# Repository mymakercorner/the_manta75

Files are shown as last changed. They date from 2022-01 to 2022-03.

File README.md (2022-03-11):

# The Manta75

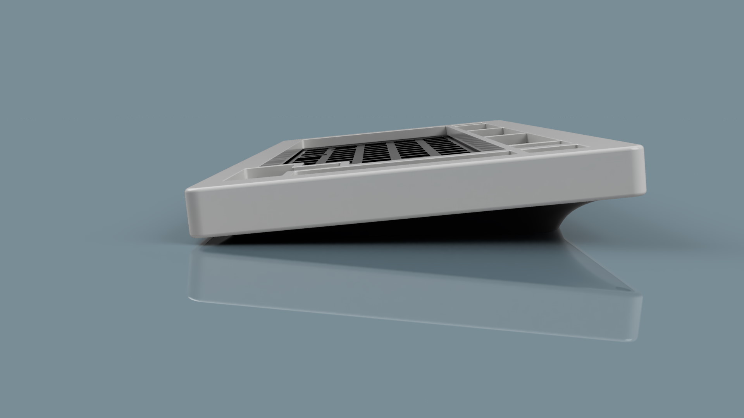
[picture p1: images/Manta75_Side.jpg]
Manta75 render


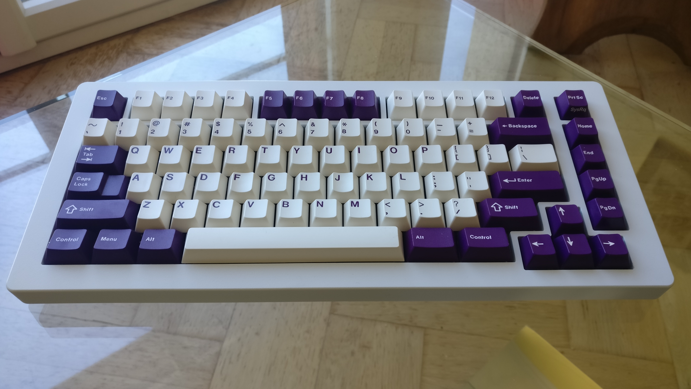
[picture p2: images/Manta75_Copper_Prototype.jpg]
Manta75 copper prototype


The Manta75 is an exploded arrows and nav clusters 75% keyboard with a curvy bottom.
It is the second project of the *Sea Collection* and as such it's name is taken from one of the species we see in our oceans, the [Manta ray](https://en.wikipedia.org/wiki/Manta_ray).

The [Satisfaction 75](https://cannonkeys.com/collections/satisfaction-75) have this similar exploded arrows/nav clusters, on the manta75 I went with no knob and screen to maximize the number of available keys.

## Features

- Two pieces case designed with Fusion360.
- PCB designed with Kicad 5.1.5.
- Bottom mount leaf spring plate design with optional friction fit gaskets.
- [Unified C3 daughterboard](https://github.com/ai03-2725/Unified-Daughterboard)
- QMK firmware with VIA and VIAL support.

## Layout options

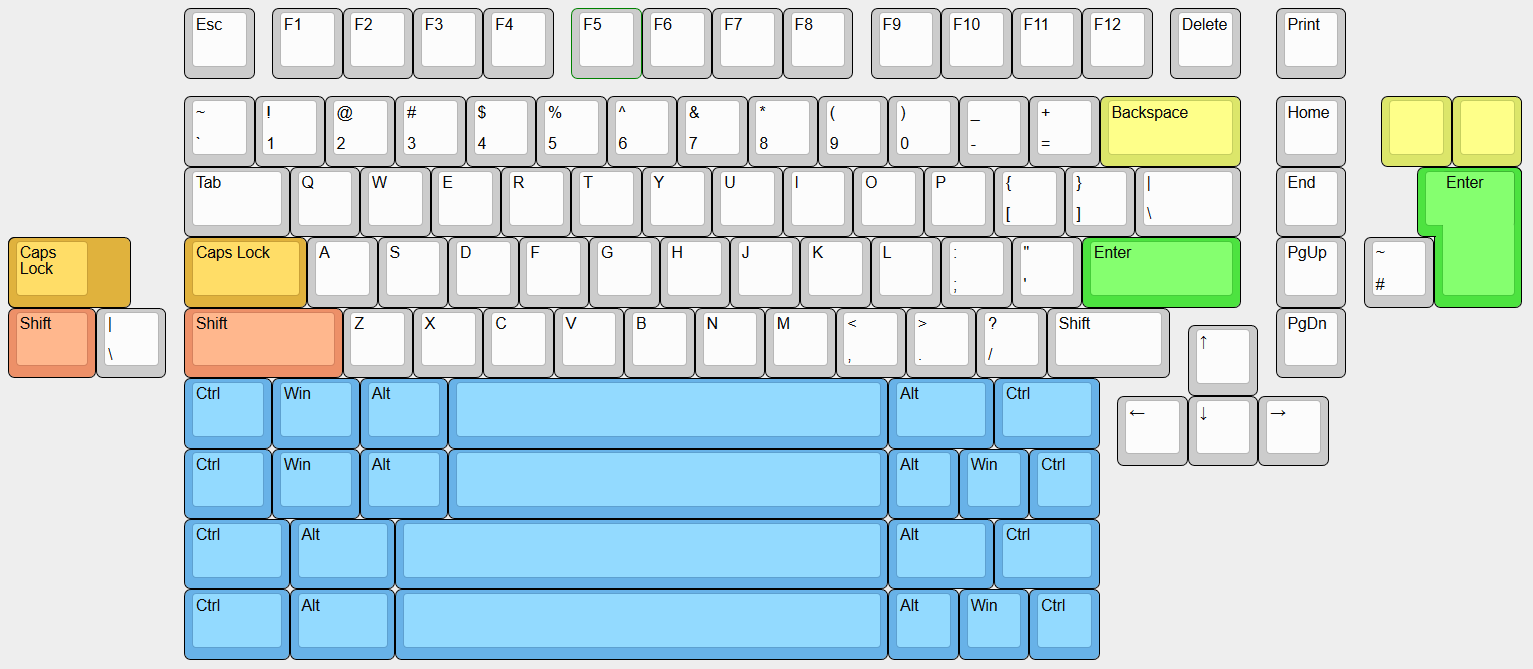
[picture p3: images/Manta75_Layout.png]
Manta75 layout options
 

## Specifications

- Typing angle: 6 degrees
- Width: ~346mm
- Height: ~150mm
- Bezels size: 15mm all around.
- Front height: 18.3mm without bumpons, 19.7mm with bumpons.
- Top plate to top case distance: 7mm.
- Bumpons: 3M (reference SJ-5382). 
- Weight:
    - Aluminium top and bottom case: ~1,46Kg
    - Alumininum top and copper bottom case: ~4Kg
- Screws:
    - 6X M2.5x10 screws for top/bottom parts.
    - 4X M2.5x4 screws for plate/bottom parts.
    - 4X M2x4 screws for USB daughterboard. 

## Licensing 

[][cc-by]

Hardware design is provided under the very permissive
[Creative Commons Attribution 4.0 International License][cc-by].

[][cc-by]

[cc-by]: http://creativecommons.org/licenses/by/4.0/
[cc-by-image]: https://licensebuttons.net/l/by/4.0/88x31.png
[cc-by-shield]: https://img.shields.io/badge/License-CC%20BY%204.0-lightgrey.svg

The goal is to allow anyone to use all hardware design files with the least restrictions possible.
This licence will allow you to make your own Manta75 and even use the hardware design files for commercial purposes.  

As for the QMK/VIA/VIAL firmware source code, it is provided on separate repositories, forks of QMK and QMK for Vial repositories.

## Design choices

### Layout

I wanted to type on the smallest layout possible but without sacrificing any usability for someone that has used no smaller than TKLs for a very long time.  

As a software engineer a keyboard is first and foremost a productivity instrument; as a result having arrow keys, nav keys and function keys without having to rely on layers is what I wanted.

75% layout seemed a good balance between compactness and usability, also wanted to separate arrow keys and nav cluster from the main keys.  
In the Manta75 you will find no screen, no knob and no badge, allowing to have a nav cluster of 5 keys instead of the usual 3 to 4 keys you can often find on other 75% keyboards. 

The goal ?  
Be able to use all my useful nav/arrow/function keys without having to rely on pressing a layer key.
The reason is that during programming sessions all those keys are already often used in combination with other mod keys (CTRL/SHIFT/ALT), adding a layer key press on top of that makes things difficult to manage (at least for me)

### Mounting

This is a leaf spring bottom mount design with only 4 fixation points.  
Having a bottom mount design makes installation of PCB/plate combo inside the case easy, even with the USB C daughterboard and JST cable. 

Gaskets can be optionally used below the leaves, friction fit placed in the bottom case.  
Length, position and material of the gaskets are up to personal preferences.
I personally uses Poron XRD of around 2cm length placed on the middle of the leaves, but it could be fun to play with other Poron types or even Sorbothane. 
No addhesive is needed to fix the gaskets as they are friction fit, the goal here is to be easily tuned to user preference and facilitate experimentation.

Physical simulations have been done in Fusion 360 to tune the thickness and length of the leaves.  
The result is a plate that is optimally tuned (to my taste) for aluminium material and that can be used without gaskets for maximum bounce.
For softer materials like FR4 the use of gaskets may be desirable.  

More details on plate design and Fusion 360 simulations can be found [HERE](PLATE_DESIGN.md).

### Case

#### Aestetics

There are 15mm bezels on all sides:
- I am a big sucker for thick bezels.
- This allowed me to accentuate the curvature on the bottom case significantly.
- Accentuating the bottom case curvature allows the screw holes not to be visible at side angles.

I wanted the bottom case to be very curvy with no obvious straight lines and to give the impression that the keyboard is floating on the desk, even from a side view of the board (the curvy bottom case helped a lot for that).

#### Functionality

The plate can move down up to 1.2mm, past that point it bottoms up on the bottom case to prevent excessive leaves distortion and switch pins shorting on the bottom case.  
There is a 1mm clearance between the plate and the top case for the plate to be able to tilt without touching it.   
There is 3.2mm clearance betweem PCB and bottom case so that the switch pins do not short the PCB when the plate is fully pressed.  
There are 4mm rails on the bottom case for optionally placing 3mm thick gaskets, those are loosely compressed by 0.2mm when the plate is assembled.

#### Machinability

Although quite curvy the case has been designed to be easily machined, even on a 3 axis CNC machine.
That does not mean it will be cheap to produce (those curves on the bottom case will take time to machine), more that there will be no big challenges for an average CNC manufacturer to make the case.

#### Picture galore

[Case renders](CASE_RENDERS.md)  
[Case received parts](CASE_PARTS.md)  
[Case photos](CASE_PHOTOS.md)

### PCB

The PCB is as simple as it can be:
- No RGB underglow.
- No per key lighting.
- Just the minimal features needed to have a stable working PCB for typing sessions.

This simplicity helped me a lot to achieve a goal that I wanted to pursue, an aestically pleasing PCB:
- Switch matrix column traces only on the top PCB.
- Switch matrix row traces and MCU traces only at the bottom PCB.
- Rounded traces with use of teardrops for switches holes.

To go further with aestetics I played with ground copper fills (only at the top PCB) and solder mask.  
This gives a bright solder mask color for the top of the PCB (because of the copper below it) and a darker solder mask color for the bottom of the PCB. This worked well on my green PCB prototypes and could work equally well for other semi-translucent solder mask colors like red, yellow, blue, violet, ...

To be user friendly all modifiers that can have different configurations are properly labelled on the silk screen. 

As for the manufacturing care has been taken it could easily be made and assembled at JLCPCB:
- All components references are from JLCPCB or it's sister company LCSC.
- Most are basic JLCPCB components to make the manufacturing cost as small as possible.
- Even the JST connector could be assembled if they happen to have some in stock (easy to solder yourself otherwise).

More details about the PCB can be found [HERE](PCB_DESIGN.md)  

## Making your own Manta75

### Risks

- Please note that all files and information here are to be used at your own risk.
- CNC manufacturing is not for the faint-hearted:
  - One-off CNC manufacturing is very expensive.
  - CNC manufacturers can make mistakes that can result in an expensive and useless chunk of metal.

### Case manufacturing

#### The data files

STEP files and drawings of top and bottom parts are available in *Case* directory.

The drawings, while far from professionally done, contains all requested information for the parts to be done by a CNC manufacturer: 
- Units used for the design (millimeters).
- Requested tolerance standard to be used during manufacturing (ISO 2768 - fine).
- All threaded holes are properly specified.
- Asked for deburring after machining.

#### About parts clearance

There is 0.15mm clearance between top and bottom parts.   
This allows to compensate for:
- CNC machining tolerancing errors.
- Parts finishing that can add to the part final thickness.

This clearance value is not universal, it's value depends on several factors:
- The confidance in your CNC manufacturer to target the given tolerance standard.
- The selected finish for earch part, each finish type adds more or less thickness to your final part.

A clearance of 0.15mm was for me suitable for the following finishing scenarios:
- Powdercoated top + raw bottom (tested).
- Powdercoated top + anodized type II bottom (not tested).
- Hard anodized type III top + raw or anodized type II bottom (not tested).
- Anodized type II top + raw or anodized type II bottom (not tested).

If you want to widen or tighten the clearance value, please do it by modifying the top case part only.

#### Selecting a CNC manufacturer

CNC services are getting more and more common nowadays:
- Some people uses 3DHubs.
- Others uses Xometry (I used Xometry EU for my Manta75 cases and for a previous project).
- Others uses Chinese manufacturers.

Please be aware that in general 'very cheap' and 'high quality' does not go well together.  
If price is a concern a solution to lower price per unit significantly is to make several units. Even doing 3 to 5 units will trop the price significantly.

### PCB manufacturing 

Kicad project is available in *Pcb/Kicad* directory.  

PCB fabrication files are available in *Pcb/Fabrication* directory.  
Those are:
- Gerber files.
- Bill of material (BOM) file.
- Pick and place (CPL) file for the assembly process.
Those are in the format that JLCPCB manufacturer expects, for you to very easily order assembled PCBs from them.
The files may need tweaking and/or modifications if you plan to go with other PCB manufacturers.   

### Plate manufacturing

Available plates data is available in *Plates* directory, both in DXF and STEP format.  
Two versions are available:
- ANSI.
- ISO.

ANSI only version gerber files of plate data for PCB manufacturing have also been added.  
Two versions are available:
- Gerber file for aluminium PCB manufacturing (tested).
- Gerber files for FR4 PCB manufacturing (untested).     

For those the layout options are limited to the following:
- 6.25u spacebar only.
- Left 1.25u CTRL/Win/ALT keys only.
- Right 1.5u CTRL/ALT keys only.
- Choice between standard or stepped Caps Lock.
- Choice between standard or split Backspace.

### QMK VIA/VIAL firmware

#### Source code repositories

QMK forked repository containing both default and VIA firmware source code for 'The Manta 75' is available at the following [link](https://github.com/mymakercorner/qmk_firmware/tree/the_manta75) in 'the_manta75' branch.

Vial-QMK forked repository containing both default VIA and VIAL firmware source code for 'The Manta 75' is available at the following  [link](https://github.com/mymakercorner/vial-qmk/tree/the_manta75) in 'the_manta75' branch.

#### Binaries

If you don't feel comfortable compiling QMK firmware yourself, brebuilt binaries for VIA and VIAL are available in the *Firmware* directory.  
VIA json file is also available to make the board recognised by VIA software.  
VIAL version of the firmware is compatible with both VIA and VIAL software.

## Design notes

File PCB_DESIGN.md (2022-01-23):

# PCB design

There have been two revisions of the PCB, Rev1 and Rev2.  
Both revisions are visually very similar and are electrically compatible so the same QMK firmware is used. 
The changes made for Rev2 have been:
- Cleaned the Kicad project so that it can be open sourced.
- Moved a few vias that were too close of some SMD pads.
- Added breakable tabs on top and bottom of the PCB.

## Rev2 PCB renders

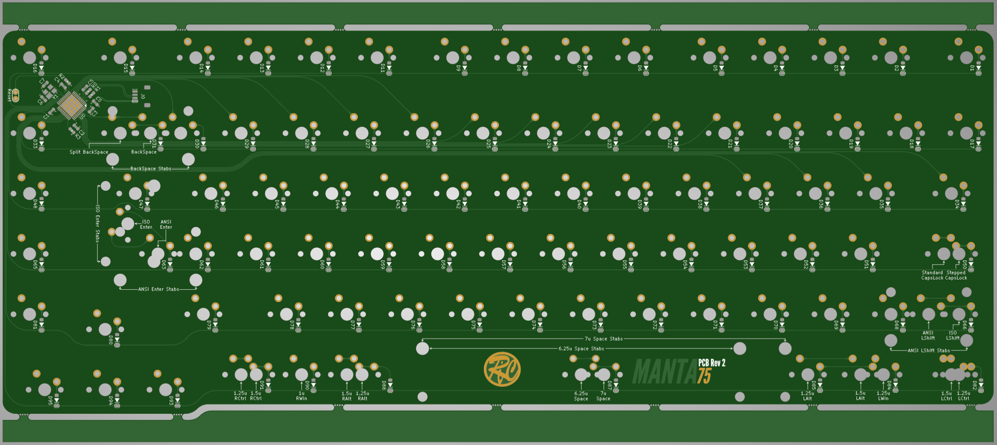
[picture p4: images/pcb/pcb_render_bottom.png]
PCB render 0

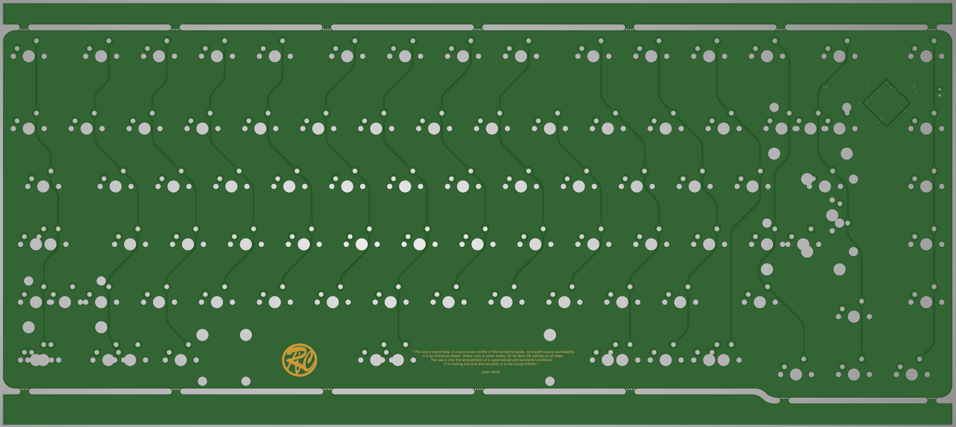
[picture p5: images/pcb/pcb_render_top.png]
PCB render 1


## Rev2 PCB photos

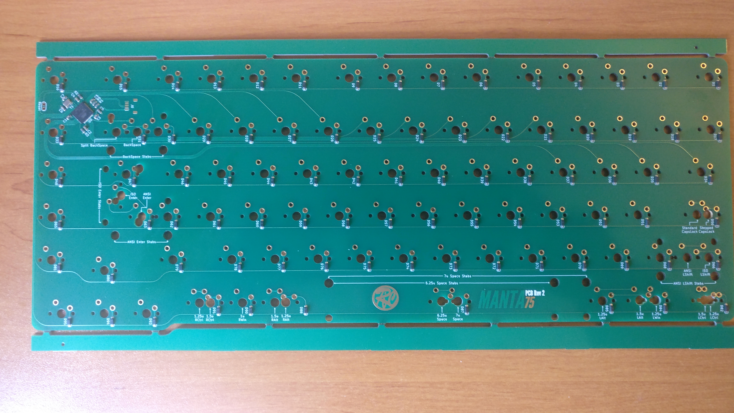
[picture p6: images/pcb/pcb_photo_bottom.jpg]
PCB photo 0

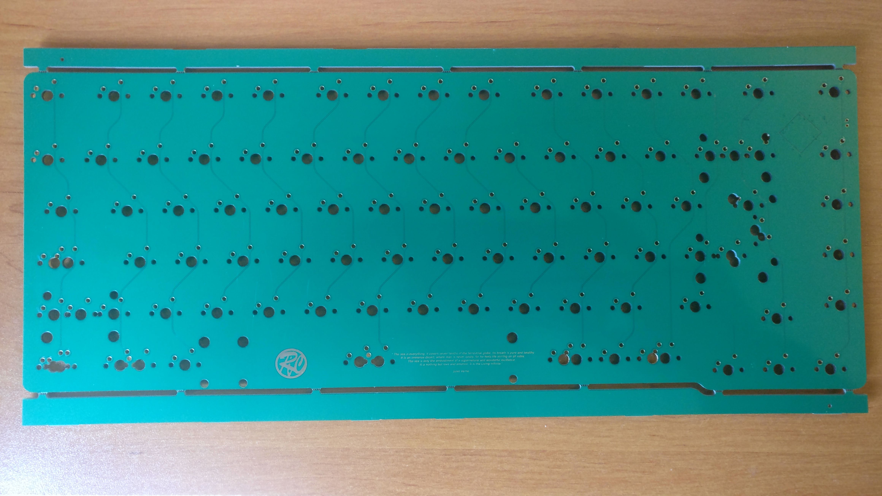
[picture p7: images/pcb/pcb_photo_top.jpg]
PCB photo 1


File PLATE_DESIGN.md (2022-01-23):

# Plate design and simulations

Plate leaf spring design and simulations have been done in Fusion 360.

## Design

Did several leaf spring designs that were not to my liking in the end.
After a few iterations I came with the top/bottom design that was a good candidate.

### Side leaf plate

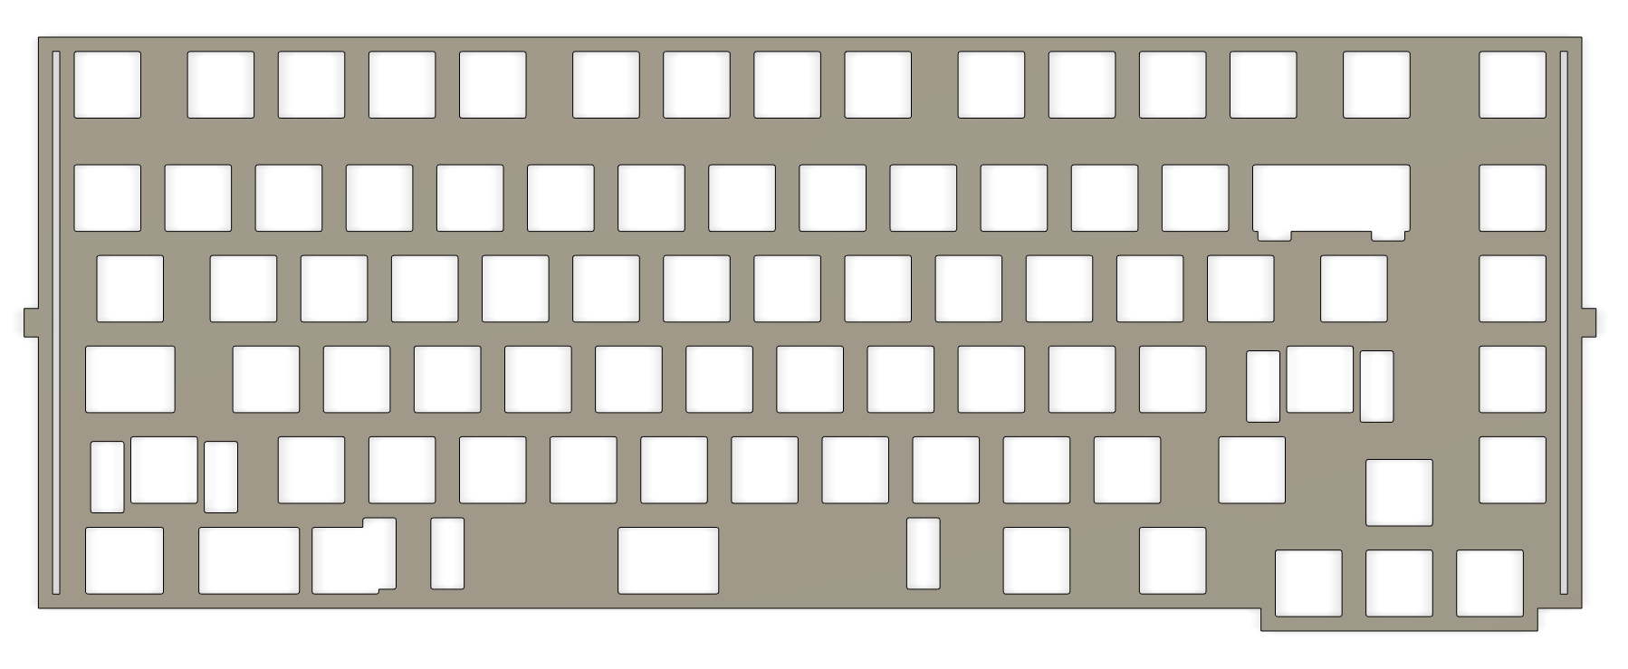
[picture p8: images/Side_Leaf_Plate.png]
Plate side leaf


I was concerned that using only two fixation points the plate assembly would not be stable enough so this has not been kept. 

### Diamond leaf plate

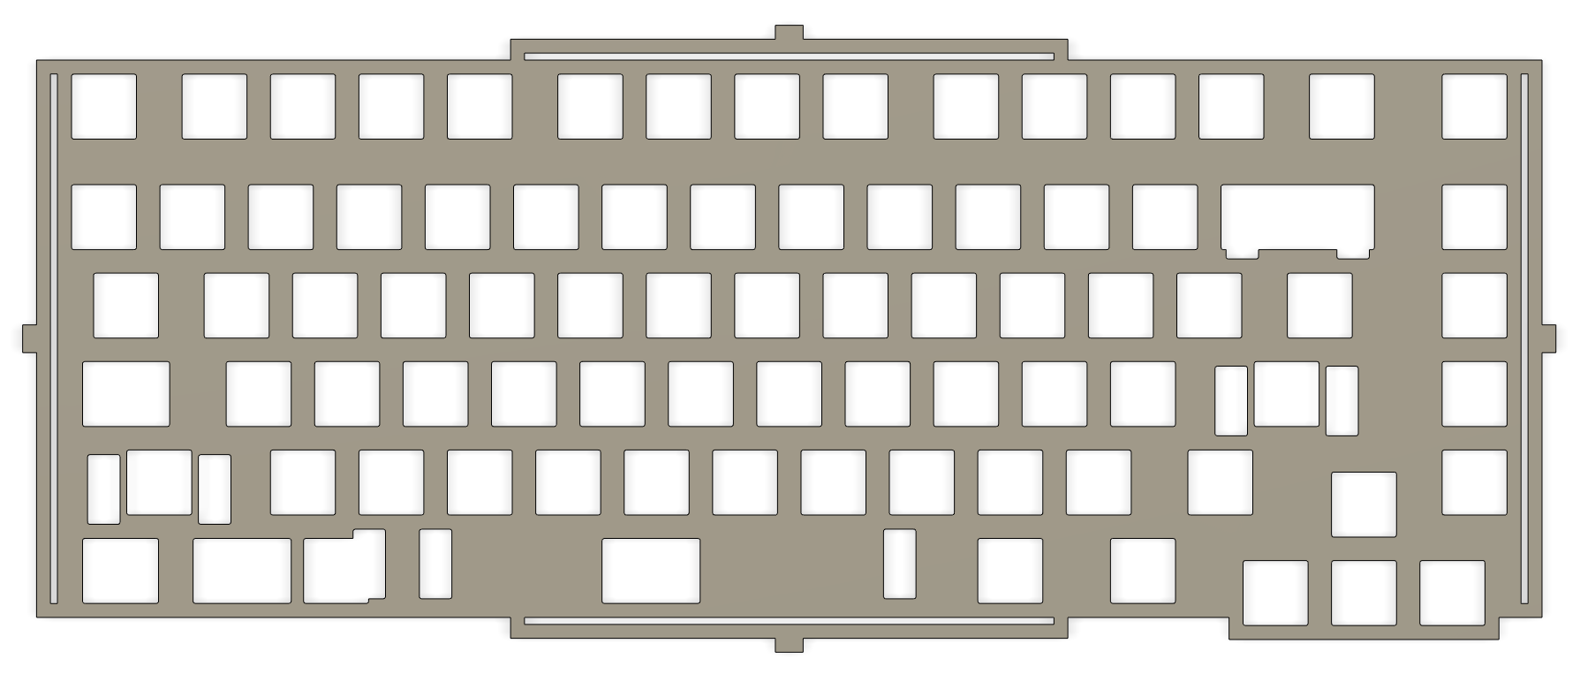
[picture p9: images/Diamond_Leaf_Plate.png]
Plate side leaf


Good stability of the plate assembly with four fixation points.  
But the case design was not done and was not sure I wanted big side bezels, having leaves on the side would have forced me to do that so I did not keep this solution as well. 

### Top/bottom leaf plate

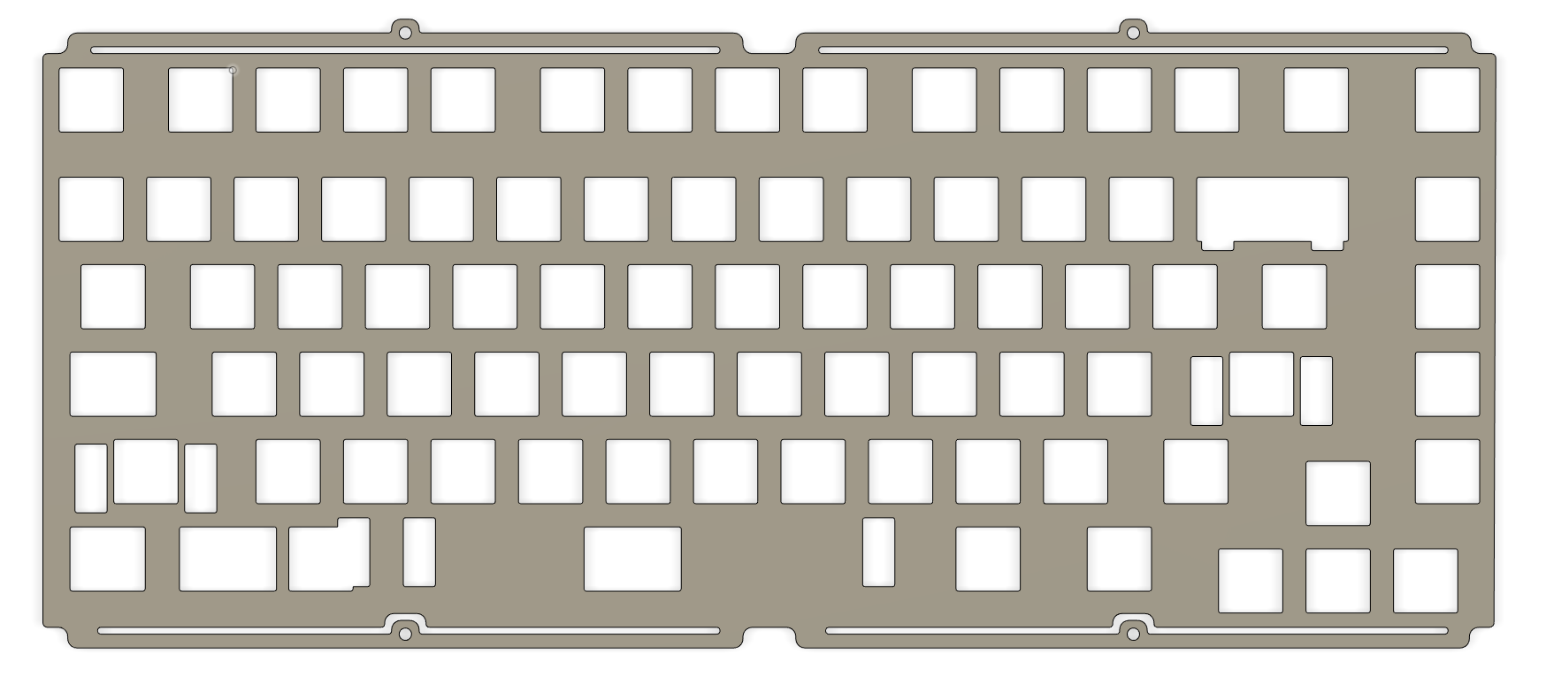
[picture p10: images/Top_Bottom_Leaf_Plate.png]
Plate top bottom leaf


Good stability of the plate assembly with four fixation points and the possibility to have thin size bezels for the case if I wanted to in the future, this is the solution that I selected.  

## Simulation

### Simulation stategy

The goal is to perform simulations that are as accurate as possible to have a good understanding of how the leaves will perform in real life.  
Using the plate as is for simulations would not have given good results as the whole plate would bend by applying a force on it.  
I wanted displacement/deformation results on the leaves only as I expected it would happen in the real case, that is take into account the whole plate + PCB + switches assembly were switches act as pillars that makes this assembly very rigid.  
Simulating this assembly is obviously very complex so I came with a much simpler solution: make the plate thicker everywere (5mm) but not on the leaves (stays at 1.5mm).
I also placed some surface areas on the plate on were I intended to apply the forces.

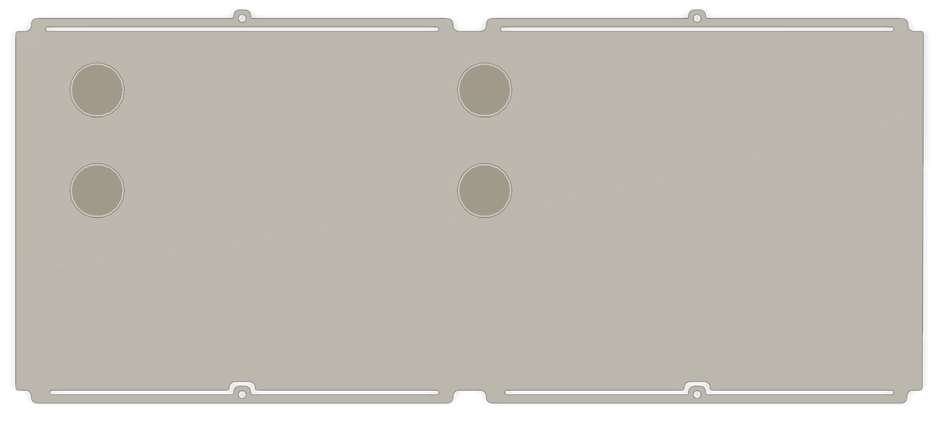
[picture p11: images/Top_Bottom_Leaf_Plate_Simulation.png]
Plate simulation image 0

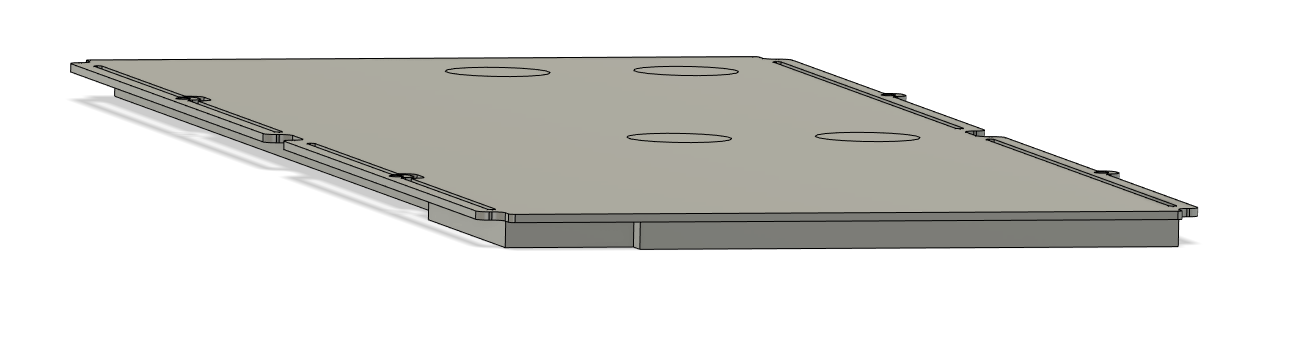
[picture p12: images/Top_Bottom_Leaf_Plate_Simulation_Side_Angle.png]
Plate simulation image 1


### Simulation results

The plate has been locked on the four fixations points and is forced to deform under forces around them.  
Tests have been conducted by applying a 20N force (around 200g) at the four surface locations modelled on the simulation plate.  
The material selected has been aluminium 6061 and gravity (weight of the plate) has not been taken into account.  
Here are 3 of the 4 simulation results, showing displacements.

#### Center press

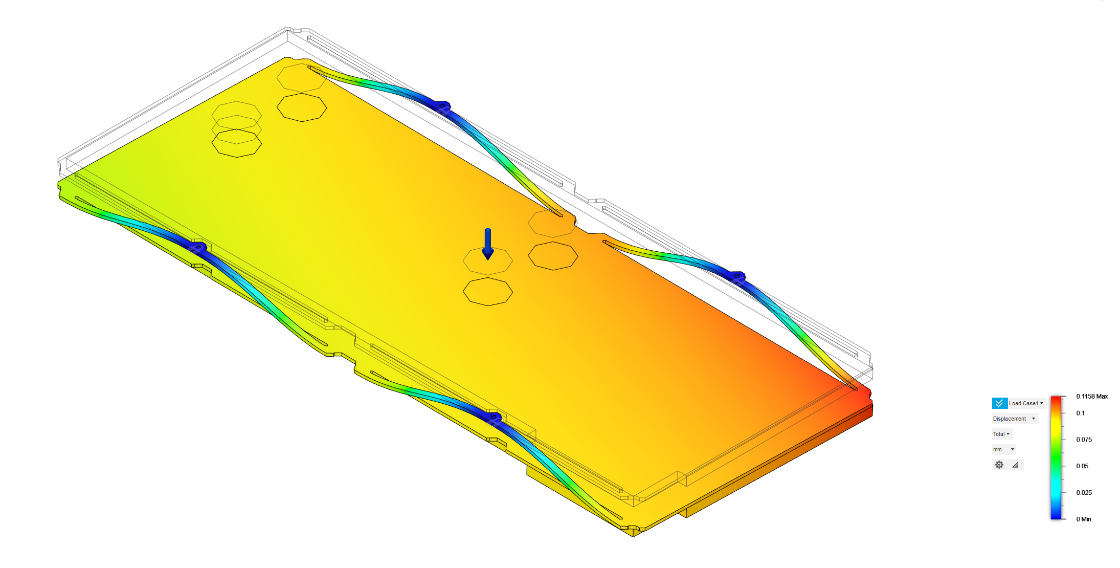
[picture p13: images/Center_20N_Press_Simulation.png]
Center Press


#### Left center press

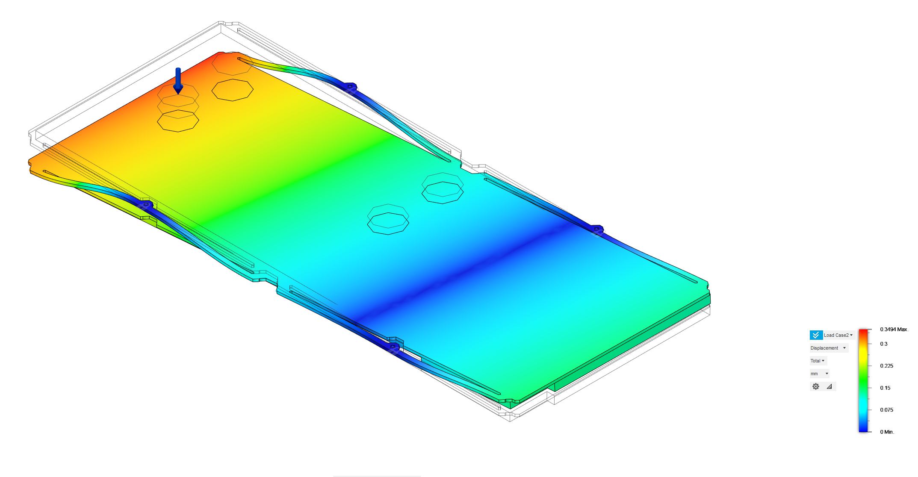
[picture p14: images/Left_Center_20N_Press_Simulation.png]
Left center Press


#### Top left press

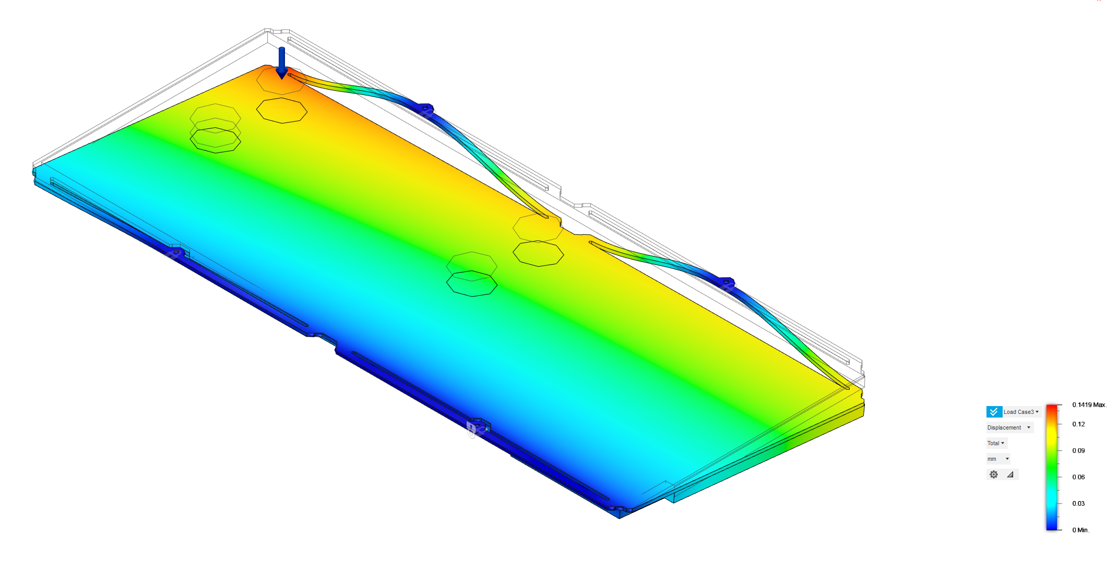
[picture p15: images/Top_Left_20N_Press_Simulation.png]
Top left Press


#### Results analysis

Top center is very similar than center left so is not included.
Displacement is uneven depending on where you apply force:
- 0.12mm for center.
- 0.14mm for top left.
- 0.35mm for center left.

I had also conducted the same simulations with the two leaves plate (side leaves) and had more uniform deformation values, but as I did not keep this solution it has been the same for the simulation results.  
We can deduce that the more you add leaves the stiffier it gets when you go to the center of the plate.  
Having four leaves looks to be a good middle ground.

## Real world tests

### Prototype plate (aluminium 5052)

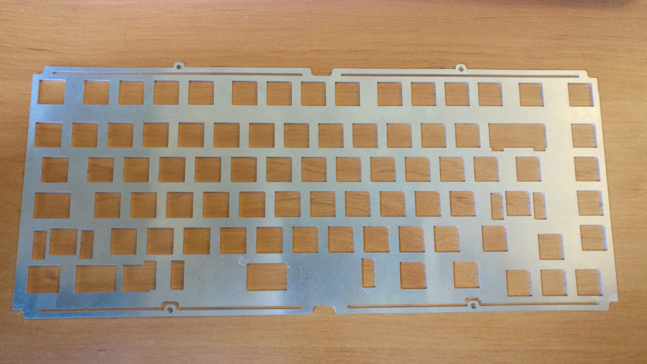
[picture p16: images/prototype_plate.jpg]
Prototype plate


### Test jig

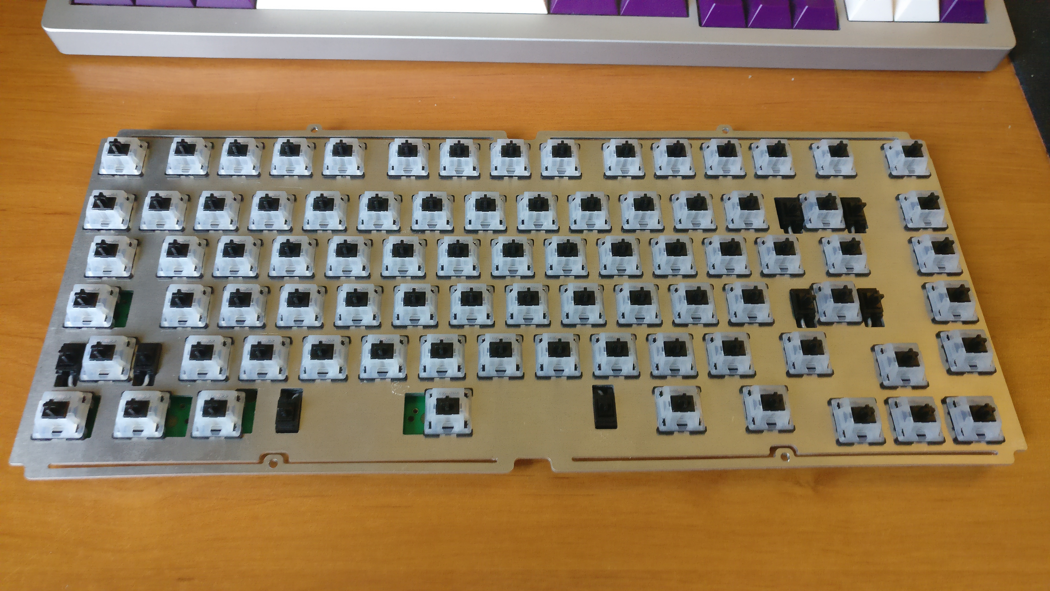
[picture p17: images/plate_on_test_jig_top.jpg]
Test jig top


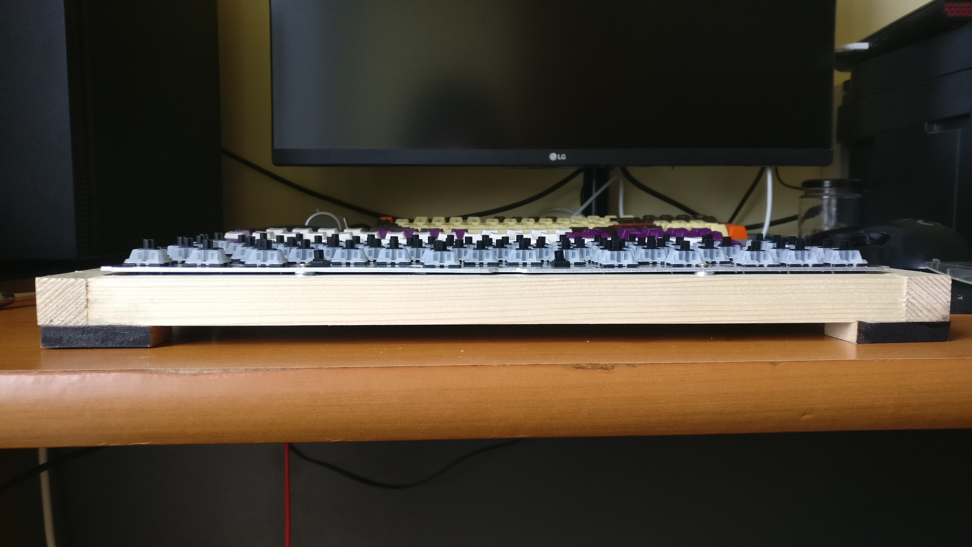
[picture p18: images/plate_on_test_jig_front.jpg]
Test jig front


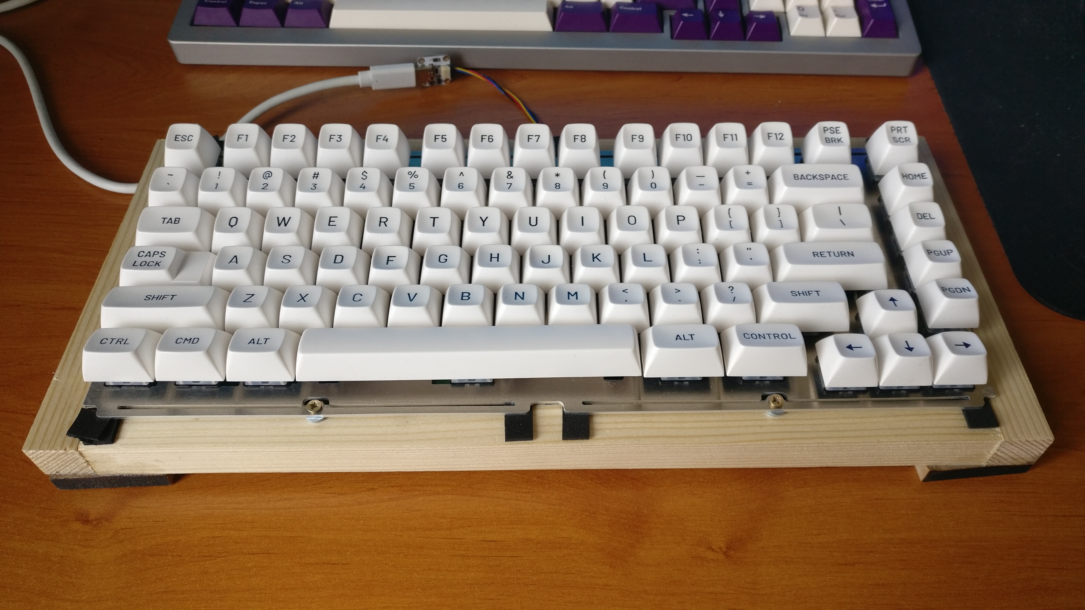
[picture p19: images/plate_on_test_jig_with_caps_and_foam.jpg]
Test jig with keycaps and foam


### Results

The whole plate moves when applying force and the unevenness of bounce seen in simulation is hardly noticable when typing. This is very close to what I was expecting with the simulations.  
This is a very bouncy feeling when typing on it.  
Also tested with foam underneath the leaves at various locations (middle of leaves, and of leaves as in the picture, ...), the more you move the foam to the end of the leaves and the more you lose the bouncy feeling.

## Final plate (aluminium PCB)

This is the end result done with aluminium PCB manufacturing.

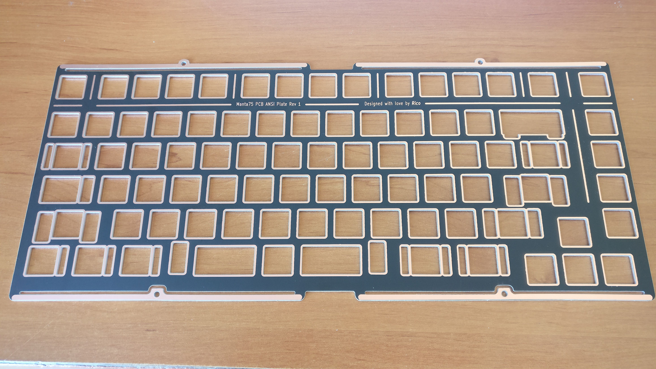
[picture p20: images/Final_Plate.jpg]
Aluminium PCB plate


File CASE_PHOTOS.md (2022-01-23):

# Parts preparation and assembly

## Mistakes were made

Despite great efforts to test fit all the parts in Fusion 360, small design errors on the bottom case prevented the plate to flex.

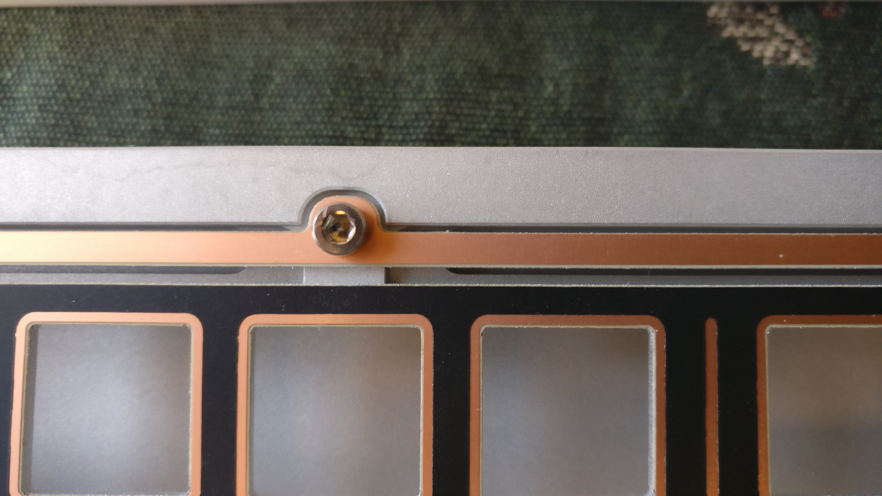
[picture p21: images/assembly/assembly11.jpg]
blooper


That's a bummer but you can't always make things right the first time, that is the purpose of doing prototypes.  
Fortunately only a bit of Dremeling on the plates fixed the issue and you can't see anything when the keyboard is fully assembled.

Note:
The STEP files for the case provided in this repository have this problem fixed.

## Bottom case polishing

The copper and one aluminium bottom case have been brushed and polished by hand.  
The bottom section have been brushed with 500 grit sand paper.  
The side sections have been sanded with 280, 500, 1000, 2000 and finally 5000 grit sandpaper. 

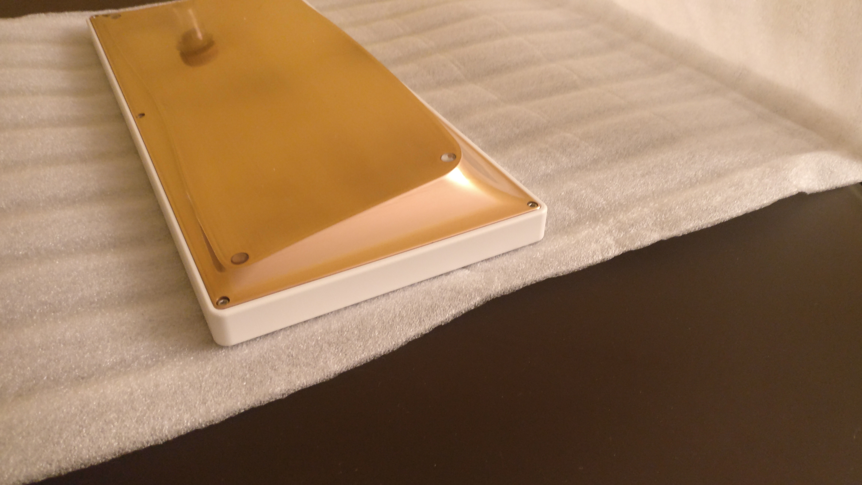
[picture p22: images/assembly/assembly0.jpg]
assembly 0

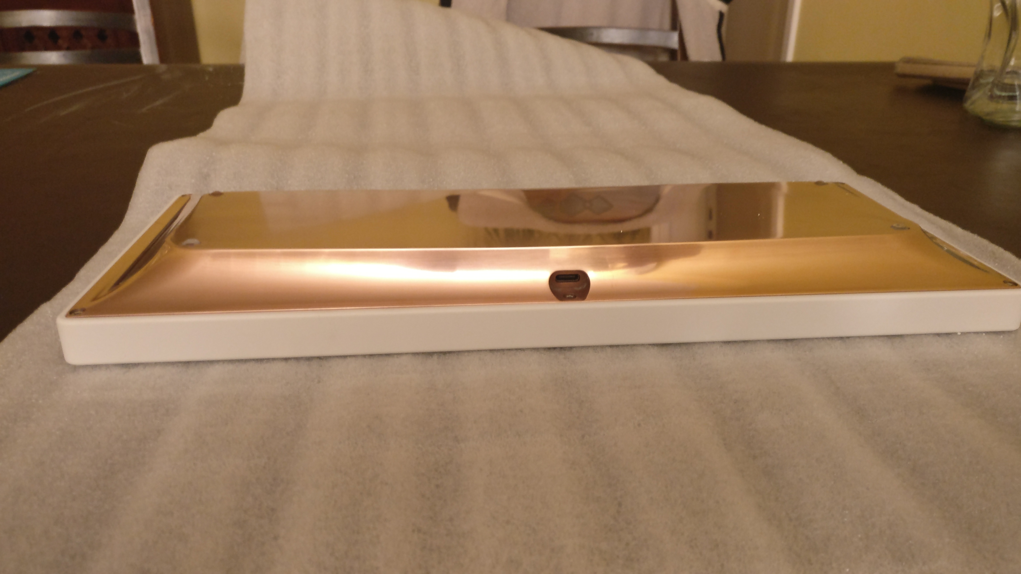
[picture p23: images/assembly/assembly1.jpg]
assembly 1

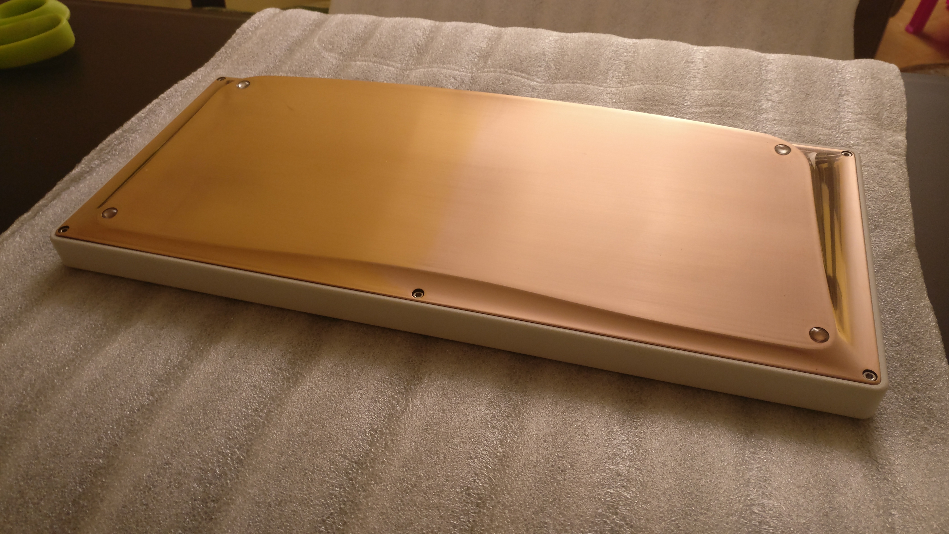
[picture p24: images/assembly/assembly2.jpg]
assembly 2

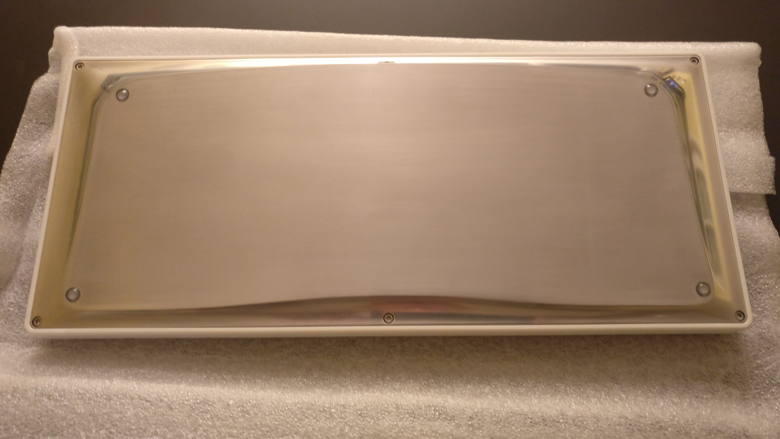
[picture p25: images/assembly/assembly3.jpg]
assembly 3

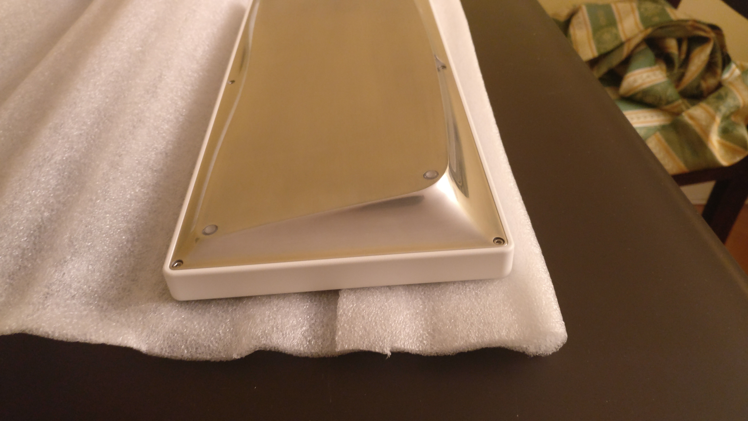
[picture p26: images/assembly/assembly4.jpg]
assembly 4


## Plate preparation and fitting

Laser cut aluminium 5052 plates have also been brushed using 500 grit sandpaper.  
You can see on the second image the dirty Dremeling work on the plate (on the top right) to allow it to freely flex.

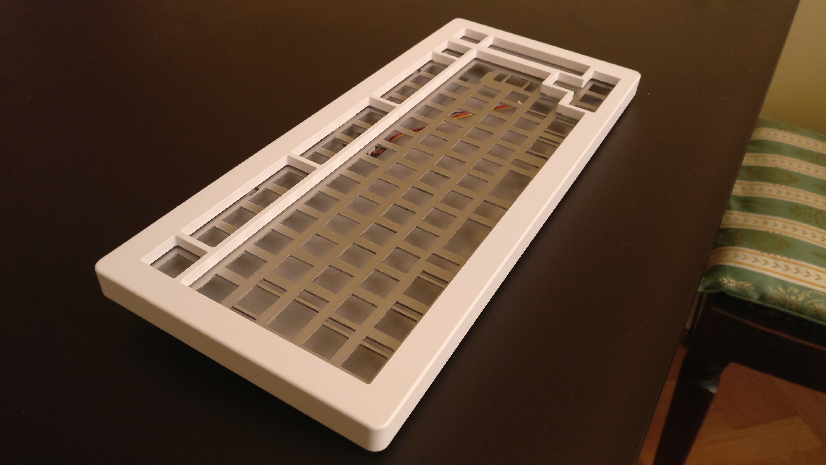
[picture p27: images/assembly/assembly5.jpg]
assembly 5

assembly 6

## Plate/PCB installation with gaskets

The gaskets have been crudely cut with a scissor on a Poron XRD sheet, not very straight and aestically pleasing but they friction fit perfectly and don't move from the bottom case grooves.  
Tested with gaskets installed on the end of the leaves and on the middle.  

You can see the copper patina done by just rubbing white vinegar on it and let it dry.

assembly 7
assembly 8
assembly 12

My preference is with the gaskets on the middle for linear switches.

assembly 9
assembly 10

## Full assembly

### My personal board with copper bottom.

assembled 0
assembled 1
assembled 3
assembled 4

### My friend's board with aluminium bottom

Using ISO AZERTY keycaps.

assembled 5
assembled 6
assembled 7

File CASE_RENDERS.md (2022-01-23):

# Renders

Render11
Render5
Render7
Render8
Render9
Render6
Render0
Render10
Render3
Render4
Render1
Render2

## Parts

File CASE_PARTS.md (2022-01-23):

# Received parts from the CNC manufacturer

Those are the parts received from the CNC manufacturer, Xometry EU.  
The bottom case parts (3 in aluminium 6061, 1 in brass) are kept raw with only a fine grit glass bead blast finish. I will not keep them all like that; the copper and one aluminium bottom will be polished by hand on the outside, the copper part will also receive a forced patina with the use of white vinegar (on the inside only).  
The top case parts(4 in aluminium 6061) have been powder coated with a matte RAL 9010 color.  

At this stage I tested that they were no fitment issues with all the parts, that is top/bottom case, plate, PCB and screws.

CNC part 0
CNC part 1
CNC part 2
CNC part 5
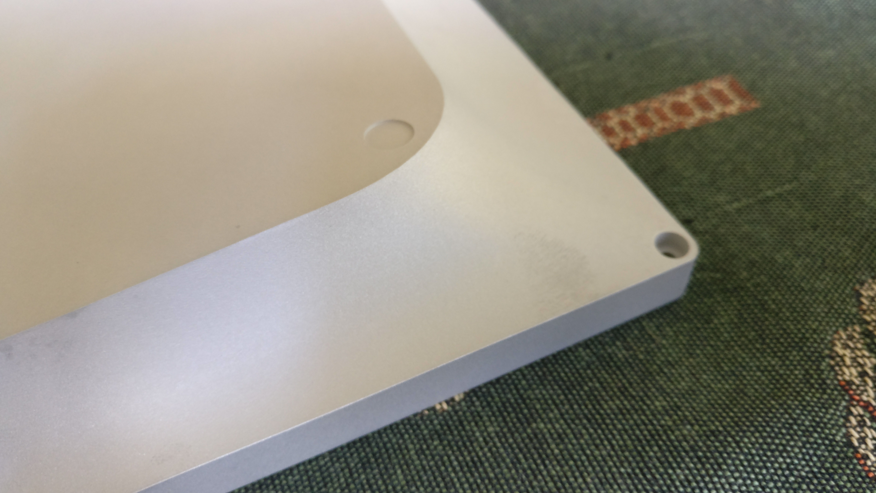
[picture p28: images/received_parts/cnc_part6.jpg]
CNC part 6

CNC part 3
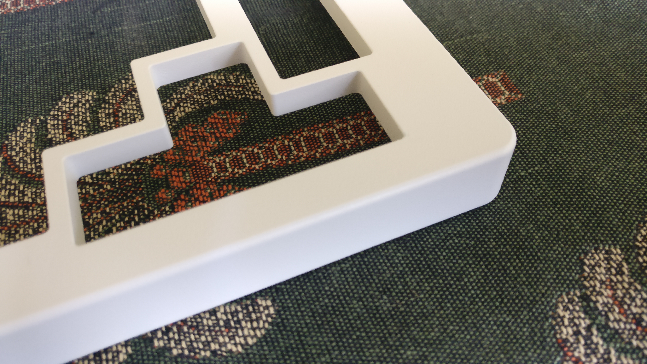
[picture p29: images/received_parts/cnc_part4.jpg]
CNC part 4

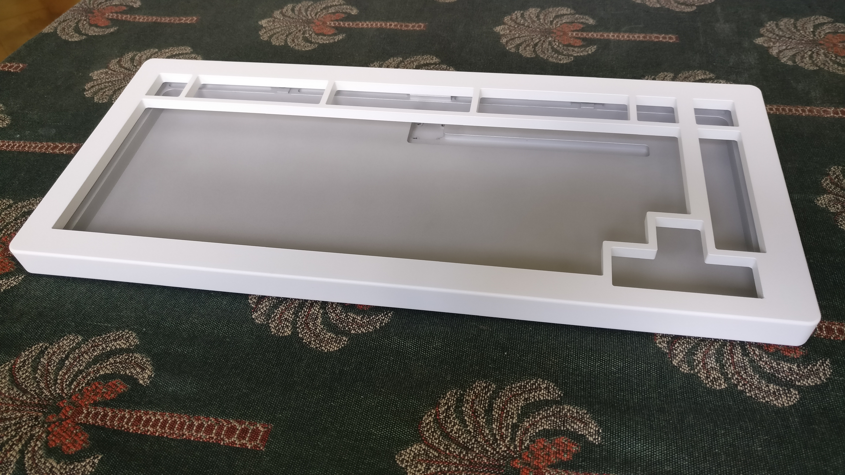
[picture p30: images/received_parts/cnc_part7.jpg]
CNC part 7

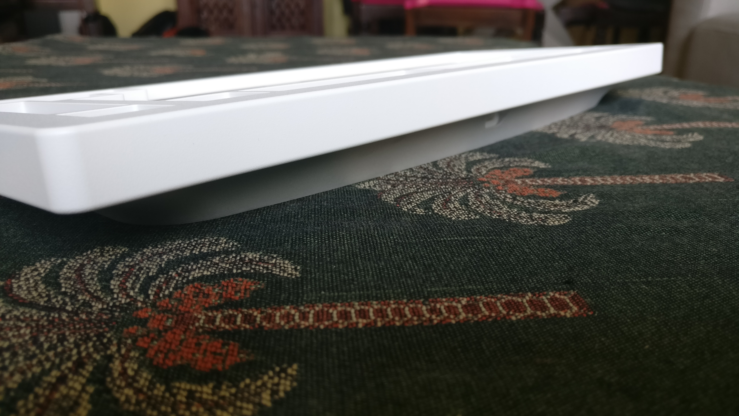
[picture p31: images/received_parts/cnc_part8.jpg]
CNC part 8

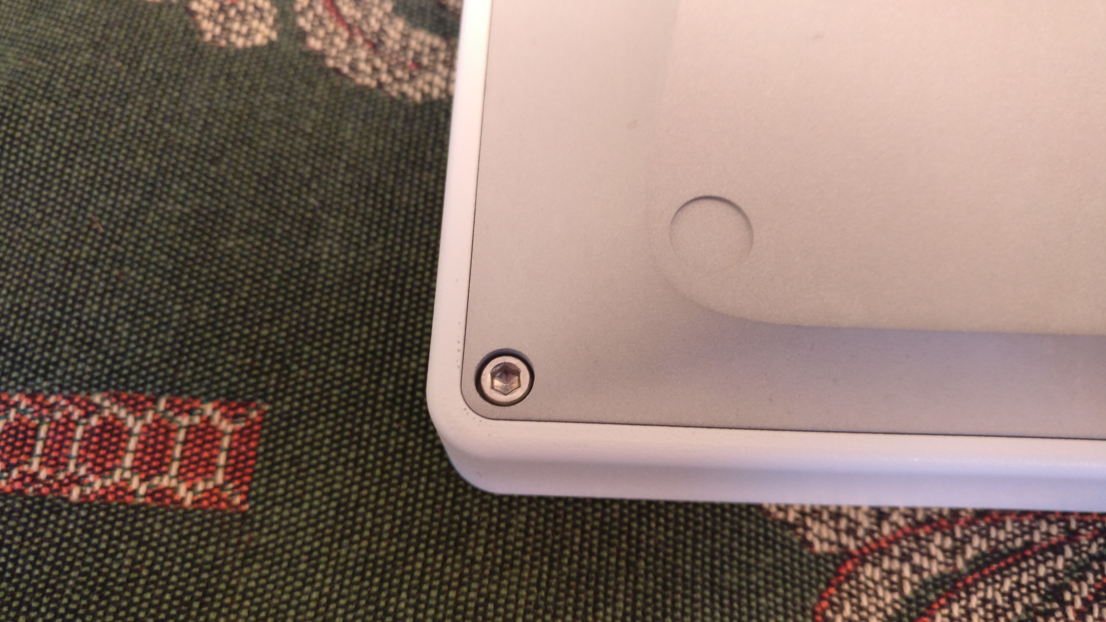
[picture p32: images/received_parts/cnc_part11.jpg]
CNC part 11

CNC part 12
CNC part 15
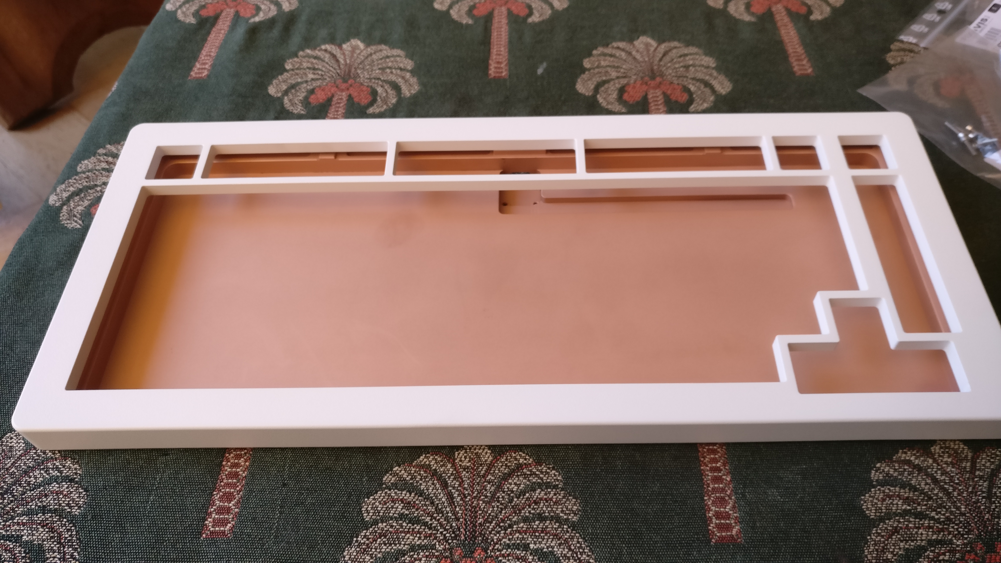
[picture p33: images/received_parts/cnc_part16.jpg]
CNC part 16

CNC part 13
CNC part 9
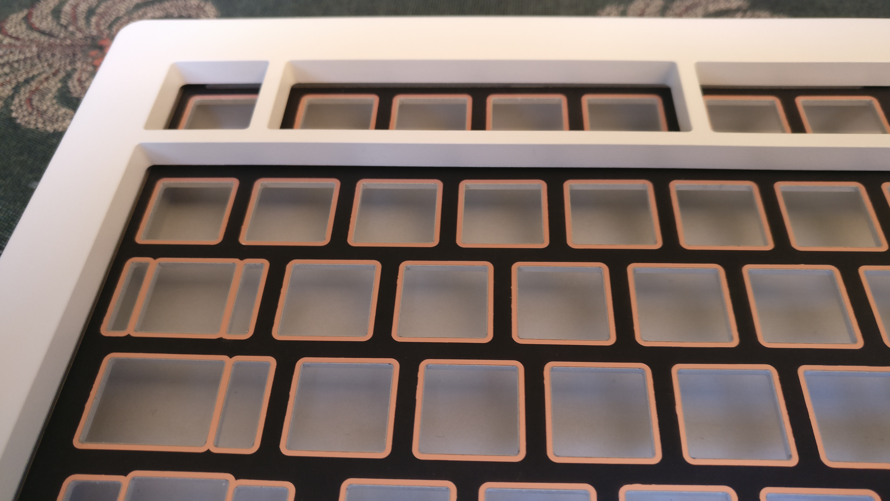
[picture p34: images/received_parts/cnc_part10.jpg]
CNC part 10


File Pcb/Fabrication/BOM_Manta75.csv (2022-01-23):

Comment | Designator | Footprint | LCSC Part Number
10uF | C0 | Rico:Capacitor_603 | C19702
0.1uF | C1 C2 C3 C4 | Rico:Capacitor_603 | C14663
1uF | C5 | Rico:Capacitor_603 | C15849
8.2pF | C7 C6 | Rico:Capacitor_603 | C1685
D_Small | D1 D2 D3 D4 D5 D6 D7 D8 D9 D11 D12 D13 D14 D15 D16 D17 D18 D19 D20 D21 D22 D23 D24 D25 D26 D27 D28 D29 D31 D33 D34 D35 D36 D37 D38 D39 D40 D41 D42 D43 D44 D45 D47 D48 D46 D50 D51 D52 D53 D54 D55 D56 D57 D58 D59 D60 D61 D62 D63 D65 D66 D68 D69 D70 D71 D72 D73 D74 D75 D76 D77 D78 D79 D80 D81 D82 D84 D85 D87 D93 D94 D95 D30 D91 D90 D88 | Rico:D_SOD-123 | C81598
JST SH | J0 | Rico:JST_SH_SM04B-SRSS-TB_1x04-1MP_P1.00mm_Horizontal | C160404
22 | R0 R1 | Rico:Resistor_603 | C23345
10K | R2 | Rico:Resistor_603 | C25804
1K | R3 | Rico:Resistor_603 | C21190
ATmega32U4-MU | U0 | Rico:QFN-44-1EP_7x7mm_P0.5mm_EP5.2x5.2mm | C45874
Crystal_16MHz | Y1 | Rico:Crystal_SMD_3225-4Pin_3.2x2.5mm | C13738

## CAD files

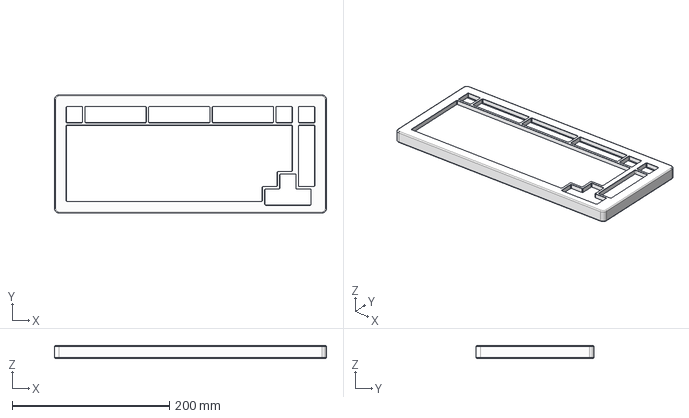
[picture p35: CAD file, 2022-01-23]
Case/Manta75_Top_Case.step
345.7 x 150.5 x 16.5 mm

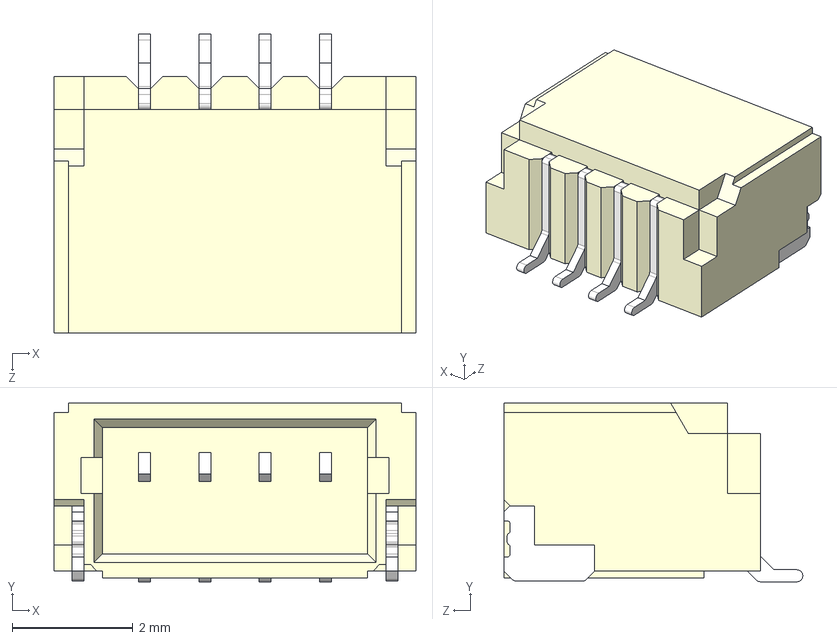
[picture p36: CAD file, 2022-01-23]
Pcb/Kicad/RicoKicadLibrary/3dModels/SM04B-SRSS-TB(LF)(SN)--3DModel-STEP-56544.STEP
6.00 x 2.96 x 4.95 mm

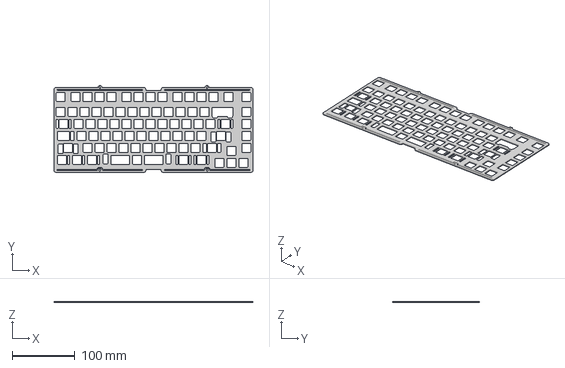
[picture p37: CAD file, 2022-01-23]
Plate/Plate_ANSI_625u.step
316.3 x 137.8 x 1.50 mm

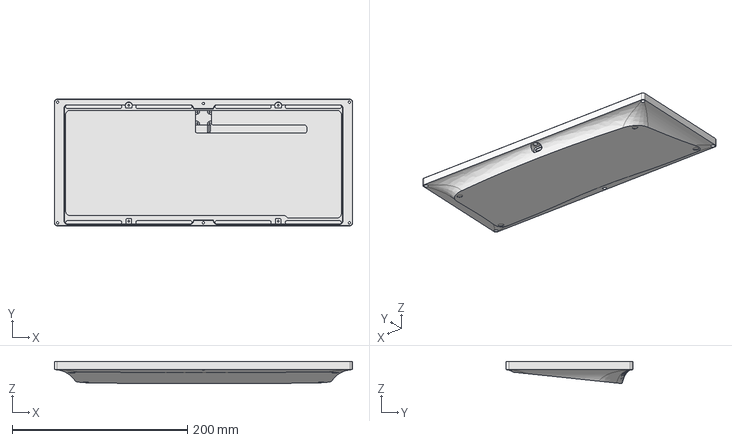
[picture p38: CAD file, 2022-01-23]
Case/Manta75_Bottom_Case.step
339.7 x 144.5 x 25.4 mm

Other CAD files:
Plate/Plate_ISO_625u.step
Plate/Plate_ANSI_625u.dxf
Plate/Plate_ISO_625u.dxf

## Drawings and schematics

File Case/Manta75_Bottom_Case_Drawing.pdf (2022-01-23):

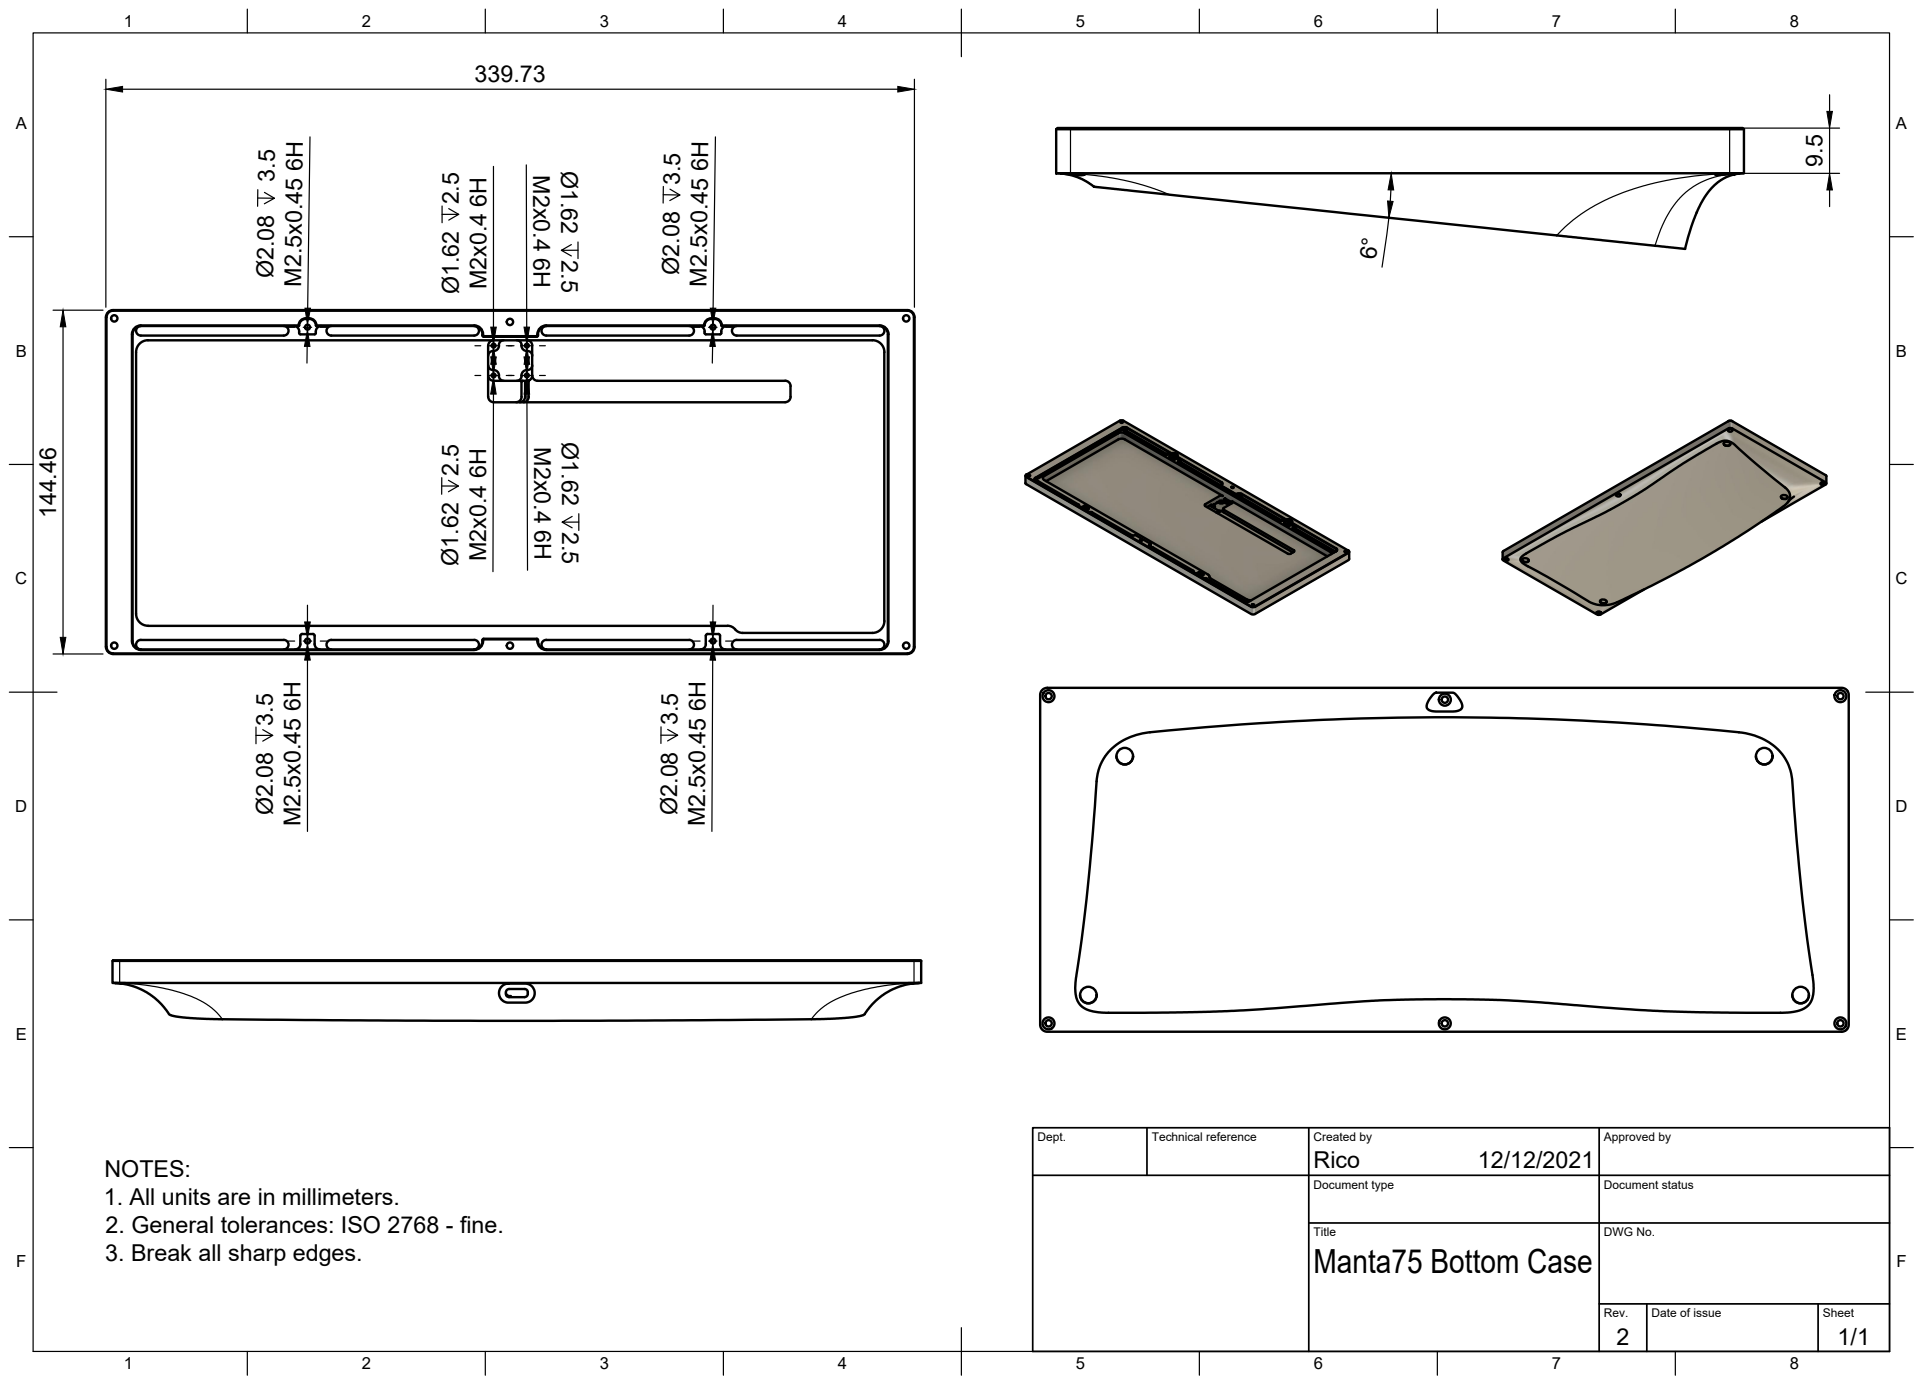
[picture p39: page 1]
Title; DWG No.; Rev.; Date of issue; Sheet; Manta75 Bottom Case

Dept. | Technical reference | Created by Rico 12/12/2021 | Approved by

NOTES:
1. All units are in millimeters.
2. General tolerances: ISO 2768 - fine.
3. Break all sharp edges.

Document type | Document status

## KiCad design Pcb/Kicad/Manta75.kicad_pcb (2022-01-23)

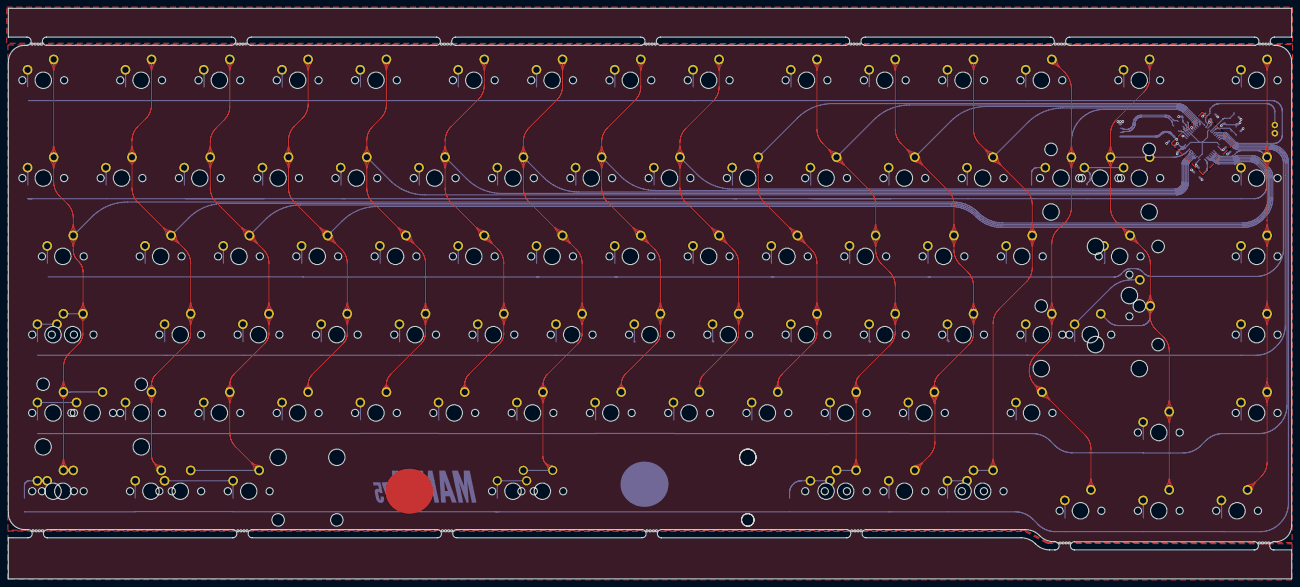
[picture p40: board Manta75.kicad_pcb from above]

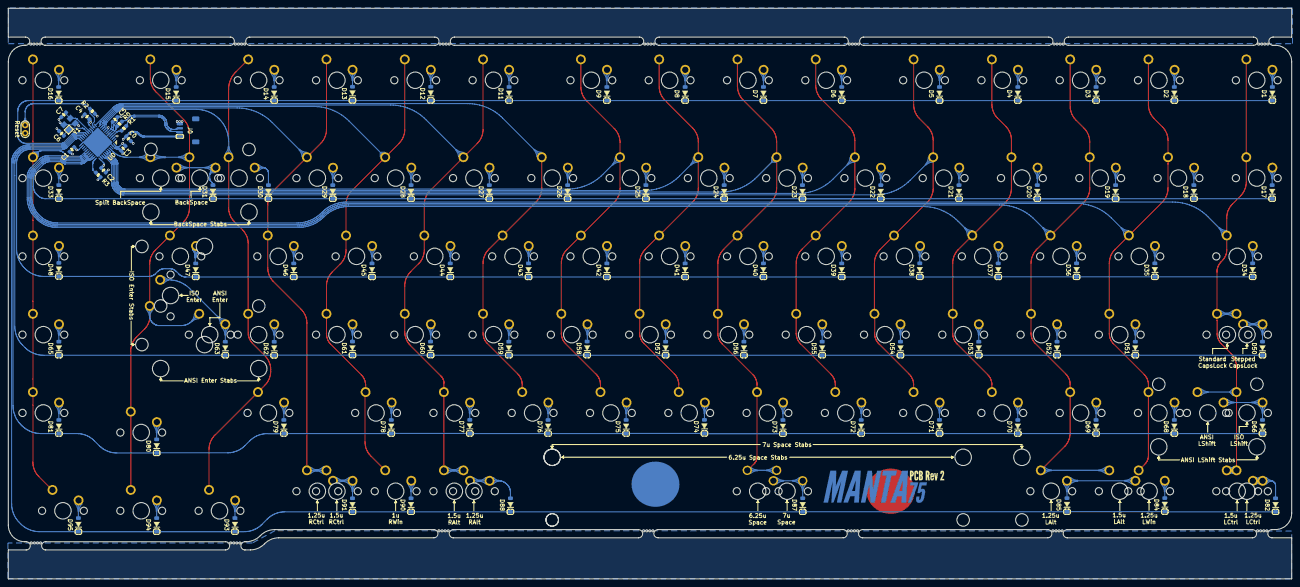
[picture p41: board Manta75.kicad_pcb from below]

Board: 2 copper layers, 312.3 x 138.8 mm, 201 parts (104 on the bottom side), 119 nets.

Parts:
C0: 10uF; Capacitor_603
C1, C2, C3, C4: 0.1uF; Capacitor_603
C5: 1uF; Capacitor_603
C6, C7: 8.2pF; Capacitor_603
D1, D2, D3, D4, D5, D6, D7, D8, D9, D11, D12, D13, D14, D15, D16, D17, D18, D19, D20, D21, D22, D23, D24, D25, D26, D27, D28, D29, D30, D31, D33, D34, D35, D36, D37, D38, D39, D40, D41, D42, D43, D44, D45, D46, D47, D48, D50, D51, D52, D53, D54, D55, D56, D57, D58, D59, D60, D61, D62, D63, D65, D66, D68, D69, D70, D71, D72, D73, D74, D75, D76, D77, D78, D79, D80, D81, D82, D84, D85, D87, D88, D90, D91, D93, D94, D95: D_Small; D_SOD-123
J0: JST SH; JST_SH_SM04B-SRSS-TB_1x04-1MP_P1.00mm_Horizontal
R0, R1: 22; Resistor_603
R2: 10K; Resistor_603
R3: 1K; Resistor_603
RST0: SW_Push; Reset_pins
Ref**: Val**; Vernes_Citation
Ref**#2, Ref**#3: Val**; Rico_Logo_Bright_Rev2
Ref**#4: Val**; Manta75_Logo_Bright_Rev2
SW1, SW2, SW3, SW4, SW5, SW6, SW7, SW8, SW9, SW11, SW12, SW13, SW14, SW15, SW16, SW17, SW18, SW19, SW20, SW21, SW22, SW23, SW24, SW25, SW26, SW27, SW28, SW29, SW30, SW32, SW33, SW35, SW36, SW37, SW38, SW39, SW40, SW41, SW42, SW43, SW44, SW45, SW46, SW48, SW51, SW52, SW53, SW54, SW55, SW56, SW57, SW58, SW59, SW60, SW61, SW62, SW65, SW68, SW69, SW70, SW71, SW72, SW73, SW74, SW75, SW76, SW77, SW78, SW80, SW81, SW88, SW90, SW91, SW93, SW94, SW95: SW_Push; Mx_Sw_1u
SW31: SW_Push; Mx_Sw_2u
SW34, SW47, SW83, SW86, SW89, SW92: SW_Push; Mx_Sw_15u
SW50, SW79: SW_Push; Mx_Sw_175u
SW63, SW67: SW_Push; Mx_Sw_225u
SW64: SW_Push; Mx_Sw_Iso
SW66, SW82, SW84, SW85: SW_Push; Mx_Sw_125u
SW87: SW_Push; Mx_Sw_625u_North_Stab
SW96: SW_Push; Mx_Sw_7u_North_Stab
SW97: SW_Push; Mx_Sw_Stepped_175u
U0: ATmega32U4-MU; QFN-44-1EP_7x7mm_P0.5mm_EP5.2x5.2mm
Y1: Crystal_16MHz; Crystal_SMD_3225-4Pin_3.2x2.5mm

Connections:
+5V: C0.1, C1.1, C2.1, C3.1, C4.1, J0.1, R2.2, U0.2, U0.7, U0.14, U0.24, U0.34, U0.44
Col0: SW1.2, SW17.2, SW34.2, SW50.2, SW66.2, SW67.2, SW82.2, SW83.2, SW97.2, U0.31
Col1: SW2.2, SW18.2, SW35.2, SW51.2, SW68.2, SW84.2, U0.30
Col2: SW3.2, SW19.2, SW36.2, SW52.2, SW69.2, SW85.2, SW86.2, U0.29
Col3: SW4.2, SW20.2, SW37.2, SW53.2, SW70.2, U0.28
Col4: SW5.2, SW21.2, SW38.2, SW54.2, SW71.2, U0.36
Col5: SW6.2, SW22.2, SW39.2, SW55.2, SW72.2, U0.37
Col6: SW7.2, SW23.2, SW40.2, SW56.2, SW73.2, SW87.2, SW96.2, U0.38
Col7: SW8.2, SW24.2, SW41.2, SW57.2, SW74.2, U0.39
Col8: SW9.2, SW25.2, SW42.2, SW58.2, SW75.2, U0.40
Col9: SW26.2, SW43.2, SW59.2, SW76.2, U0.12
Col10: SW11.2, SW27.2, SW44.2, SW60.2, SW77.2, SW88.2, SW89.2, U0.11
Col11: SW12.2, SW28.2, SW45.2, SW61.2, SW78.2, SW90.2, U0.10
Col12: SW13.2, SW29.2, SW46.2, SW91.2, SW92.2, U0.9
Col13: SW14.2, SW30.2, SW62.2, SW79.2, SW93.2, U0.8
Col14: SW15.2, SW31.2, SW32.2, SW47.2, SW63.2, SW64.2, SW80.2, SW94.2, U0.41
Col15: SW16.2, SW33.2, SW48.2, SW65.2, SW81.2, SW95.2, U0.27
D+: J0.3, R0.2
D-: J0.2, R1.2
GND: C0.2, C1.2, C2.2, C3.2, C4.2, C5.2, C6.2, C7.2, J0.4, R3.1, RST0.2, U0.5, U0.15, U0.23, U0.35, U0.43, U0.45, Y1.2, Y1.4
unnamed: C5.1, U0.6
unnamed: C6.1, U0.17, Y1.1
unnamed: C7.1, U0.16, Y1.3
unnamed: D1.2, SW1.1
unnamed: D2.2, SW2.1
unnamed: D3.2, SW3.1
unnamed: D4.2, SW4.1
unnamed: D5.2, SW5.1
unnamed: D6.2, SW6.1
unnamed: D7.2, SW7.1
unnamed: D8.2, SW8.1
unnamed: D9.2, SW9.1
unnamed: D11.2, SW11.1
unnamed: D12.2, SW12.1
unnamed: D13.2, SW13.1
unnamed: D14.2, SW14.1
unnamed: D15.2, SW15.1
unnamed: D16.2, SW16.1
unnamed: D17.2, SW17.1
unnamed: D18.2, SW18.1
unnamed: D19.2, SW19.1
unnamed: D20.2, SW20.1
unnamed: D21.2, SW21.1
unnamed: D22.2, SW22.1
unnamed: D23.2, SW23.1
unnamed: D24.2, SW24.1
unnamed: D25.2, SW25.1
unnamed: D26.2, SW26.1
unnamed: D27.2, SW27.1
unnamed: D28.2, SW28.1
unnamed: D29.2, SW29.1
unnamed: D30.2, SW30.1
unnamed: D31.2, SW31.1, SW32.1
unnamed: D33.2, SW33.1
unnamed: D34.2, SW34.1
unnamed: D35.2, SW35.1
unnamed: D36.2, SW36.1
unnamed: D37.2, SW37.1
unnamed: D38.2, SW38.1
unnamed: D39.2, SW39.1
unnamed: D40.2, SW40.1
unnamed: D41.2, SW41.1
unnamed: D42.2, SW42.1
unnamed: D43.2, SW43.1
unnamed: D44.2, SW44.1
unnamed: D45.2, SW45.1
unnamed: D46.2, SW46.1
unnamed: D47.2, SW47.1
unnamed: D48.2, SW48.1
unnamed: D50.2, SW50.1, SW97.1
unnamed: D51.2, SW51.1
unnamed: D52.2, SW52.1
unnamed: D53.2, SW53.1
unnamed: D54.2, SW54.1
unnamed: D55.2, SW55.1
unnamed: D56.2, SW56.1
unnamed: D57.2, SW57.1
unnamed: D58.2, SW58.1
unnamed: D59.2, SW59.1
unnamed: D60.2, SW60.1
unnamed: D61.2, SW61.1
unnamed: D62.2, SW62.1
unnamed: D63.2, SW63.1, SW64.1
unnamed: D65.2, SW65.1
unnamed: D66.2, SW66.1, SW67.1
unnamed: D68.2, SW68.1
unnamed: D69.2, SW69.1
unnamed: D70.2, SW70.1
unnamed: D71.2, SW71.1
unnamed: D72.2, SW72.1
unnamed: D73.2, SW73.1
unnamed: D74.2, SW74.1
unnamed: D75.2, SW75.1
unnamed: D76.2, SW76.1
unnamed: D77.2, SW77.1
unnamed: D78.2, SW78.1
unnamed: D79.2, SW79.1
unnamed: D80.2, SW80.1
unnamed: D81.2, SW81.1
unnamed: D82.2, SW82.1, SW83.1
unnamed: D84.2, SW84.1
unnamed: D85.2, SW85.1, SW86.1
unnamed: D87.2, SW87.1, SW96.1
unnamed: D88.2, SW88.1, SW89.1
unnamed: D90.2, SW90.1
unnamed: D91.2, SW91.1, SW92.1
unnamed: D93.2, SW93.1
unnamed: D94.2, SW94.1
unnamed: D95.2, SW95.1
unnamed: R0.1, U0.4
unnamed: R1.1, U0.3
unnamed: R3.2, U0.33
Reset: R2.1, RST0.1, U0.13
Row0: D1.1, D2.1, D3.1, D4.1, D5.1, D6.1, D7.1, D8.1, D9.1, D11.1, D12.1, D13.1, D14.1, D15.1, D16.1, U0.18
Row1: D17.1, D18.1, D19.1, D20.1, D21.1, D22.1, D23.1, D24.1, D25.1, D26.1, D27.1, D28.1, D29.1, D30.1, D31.1, D33.1, U0.32
Row2: D34.1, D35.1, D36.1, D37.1, D38.1, D39.1, D40.1, D41.1, D42.1, D43.1, D44.1, D45.1, D46.1, D47.1, D48.1, U0.22
Row3: D50.1, D51.1, D52.1, D53.1, D54.1, D55.1, D56.1, D57.1, D58.1, D59.1, D60.1, D61.1, D62.1, D63.1, D65.1, U0.21
Row4: D66.1, D68.1, D69.1, D70.1, D71.1, D72.1, D73.1, D74.1, D75.1, D76.1, D77.1, D78.1, D79.1, D80.1, D81.1, U0.20
Row5: D82.1, D84.1, D85.1, D87.1, D88.1, D90.1, D91.1, D93.1, D94.1, D95.1, U0.19

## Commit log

2022-01-23 [feature] Creation of the manta75 project
    [BOM_Manta75.csv, Manta75.kicad_pcb, Manta75.sch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]
2022-03-11 [feature] Added gerber files for plate PCB manufacturing, added screws specification in readme file.
